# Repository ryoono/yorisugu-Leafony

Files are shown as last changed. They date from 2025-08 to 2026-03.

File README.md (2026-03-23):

# yorisugu-Leafony

MCPC主催 第6回ナノコン応用コンテスト応募作品（最優秀賞）  

## 特徴
- カメラ不要の物体認識（透過光シルエットのみで識別）
- マイコン単体（ATmega328P）でAI推論（ロジスティック回帰）
- 消費電力70mW以下（ボタン電池駆動可能）

## デモ動画
きのこの山とたけのこの里を分類する様子および技術背景をまとめた動画です。  

- ニコニコ動画: https://www.nicovideo.jp/watch/sm46081919

## 概要

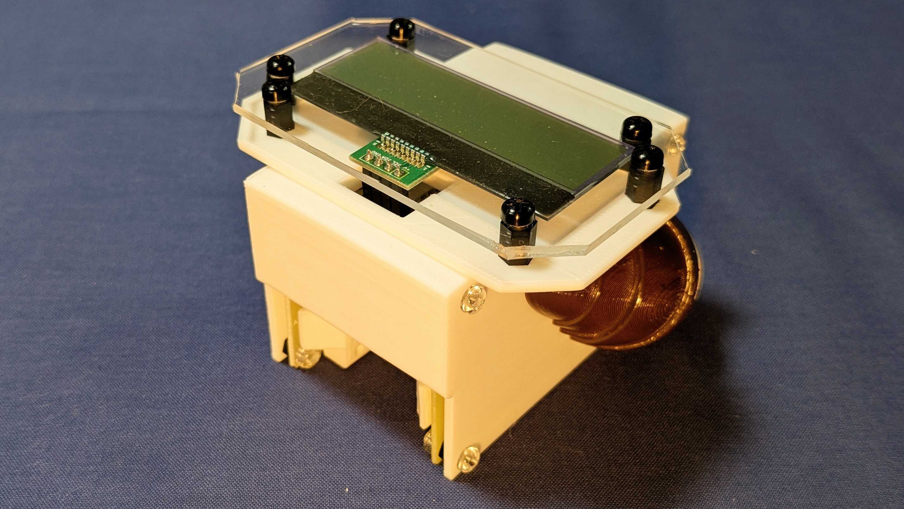
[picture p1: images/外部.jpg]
  

選りすぐLeafony  
*A low-power silhouette-based object classifier using Leafony.*  

近年、農業や製造業の現場では、形状認識のためにAIによる画像認識の導入が進んでいます。しかし、多くのシステムは高解像度カメラやGPU搭載コンピュータを必要とし、導入コストや消費電力が障壁となっています。  

本プロジェクトでは、LEDと光センサを用いて取得した「シルエット情報（透過光の強度パターン）」のみで物体を識別する、低コスト・省電力な認識手法を提案します。カメラや画像処理を使わず、マイコン1つで処理が完結するため、非常に低い消費電力で動作します。  

本プロジェクトは概念実証（PoC）として、明治製菓の「きのこの山」と「たけのこの里」を分類するデモ装置を製作し、日常的な題材を通じて技術の可能性を示しました。  

## 省電力化への取り組み

### 設計思想  
本システムではAI推論をマイコン（ATmega328P 3.3V 8MHz）上で行うことで、PCやGPUと比較して圧倒的に低い消費電力（瞬間電力70mW以内）を実現しています。これにより、ボタン電池での駆動が可能です。  

エッジAIは、計算量や精度の関係からロジスティック回帰モデルを採用しています。  

### ハードウェア設計  
マイコン1つと18個のLED/光センサによるシンプルな構成とし、最大瞬間電流を抑えるためにアナログマルチプレクサ機構を採用しています。これにより、1度に電源供給されるLED/光センサは3つで、6回に分けて電源供給されます。  

電源供給はFETで制御し、未使用時は完全に電源遮断することで待機電力を削減しています。  

### ソフトウェア設計  
本概念実証では、ひとまず1秒に1度処理を実行することとし、演算中（約3ms）以外はスリープモードにしています。  
また、シルエット情報内に物体が無いと判断された際は推論をパスし、演算時間を削減しています。  

## 回路図
基板はLED投光用と光センサ受光用の2枚が用意されます。2つの基板は向かい合わせに設置され、間にある対象物のシルエットを取得します。  

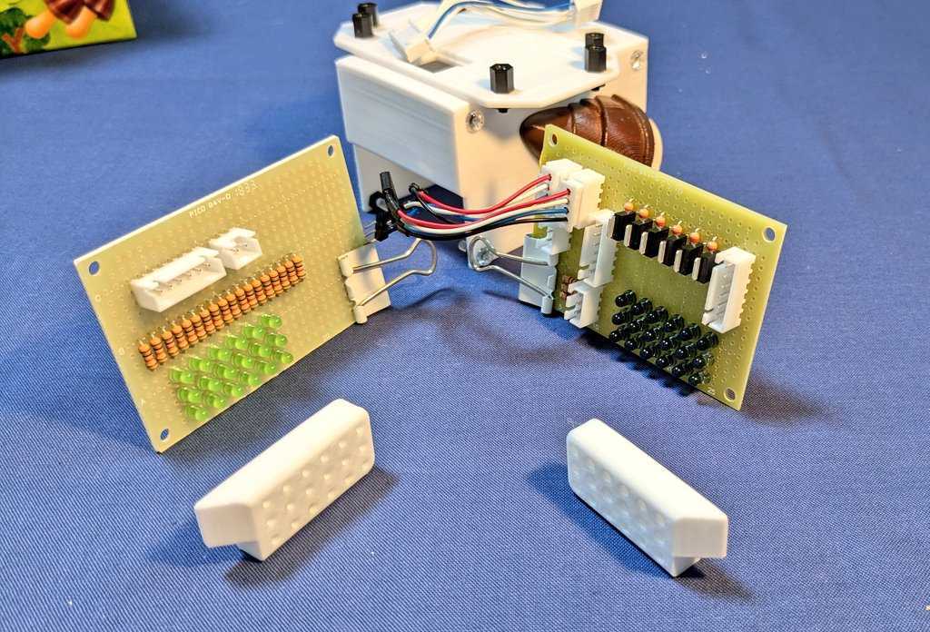
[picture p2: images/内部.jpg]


光センサ受光用基板  

  

LED投光用基板  

  

## ソフトウェア

[ソースコード](./Leafony_src/print_classification_result/)を参照

シルエットデータの取得、特徴量生成、ロジスティック回帰による推論、LCD表示を行うメイン処理です。

## 検証
本システムの有効性を確認するため、分類精度および処理性能の評価を行いました。

### データ取得
各サンプルは実機を用いて取得し、LED/光センサの出力値を特徴量として各パターンで約100ケースずつ記録しました。  
データは学習用と評価用に分割し、モデルの学習を行っています。

取得したデータをヒートマップにしたものが以下で、目視でもなんとなくお菓子のシルエットが分かります。（数値が小さい方が影）

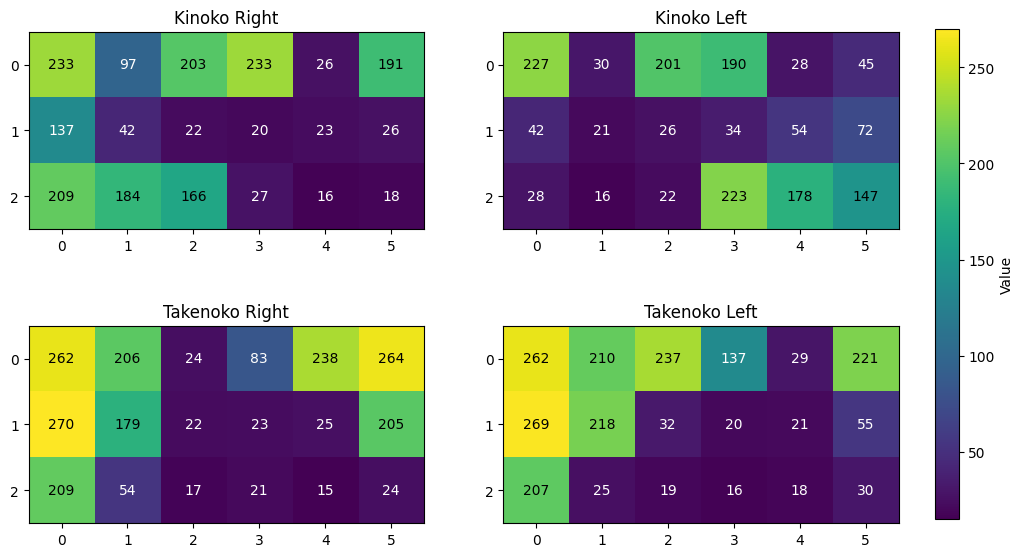
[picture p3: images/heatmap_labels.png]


### 分類結果

実機を使用して取得した[データセット](./Leafony_src/send_sens_val/raw_data/kinoko_takenoko_merged.csv)を用いてPC上で正答率を算出した結果と、結果表示画面を以下にまとめます。  

| Class | Precision | Recall | F1-score | Support |
|---:|---:|---:|---:|---:|
| 0(kinoko_right) | 1.0000 | 0.9896 | 0.9948 | 96 |
| 1(kinoko_left) | 1.0000 | 1.0000 | 1.0000 | 95 |
| 2(takenoko_right) | 0.9897 | 1.0000 | 0.9948 | 96 |
| 3(takenoko_left) | 1.0000 | 1.0000 | 1.0000 | 98 |
| **Accuracy** | — | — | **0.9974** | 385 |
| **Macro avg** | 0.9974 | 0.9974 | 0.9974 | 385 |
| **Weighted avg** | 0.9974 | 0.9974 | 0.9974 | 385 |

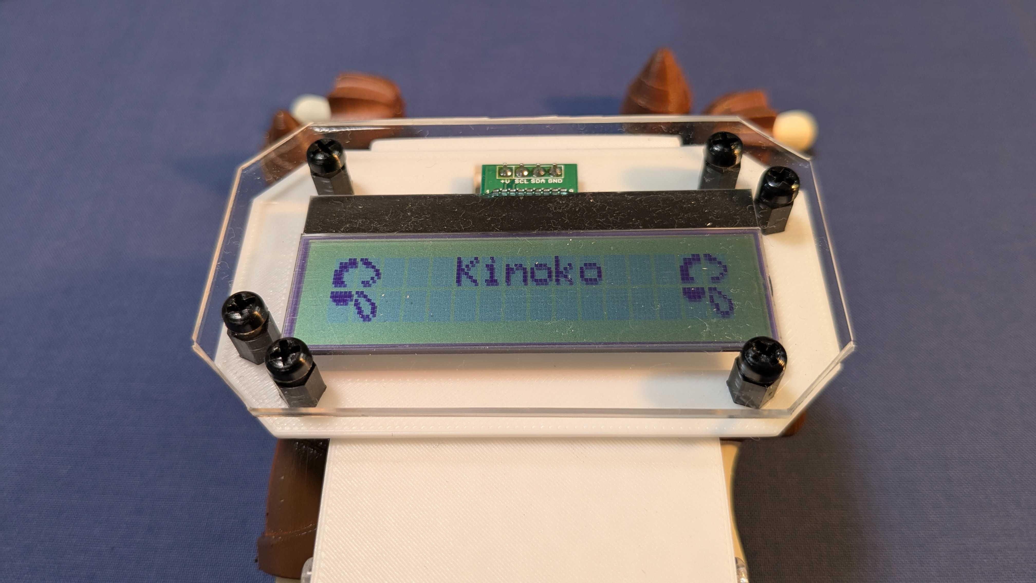
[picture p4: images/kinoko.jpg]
  

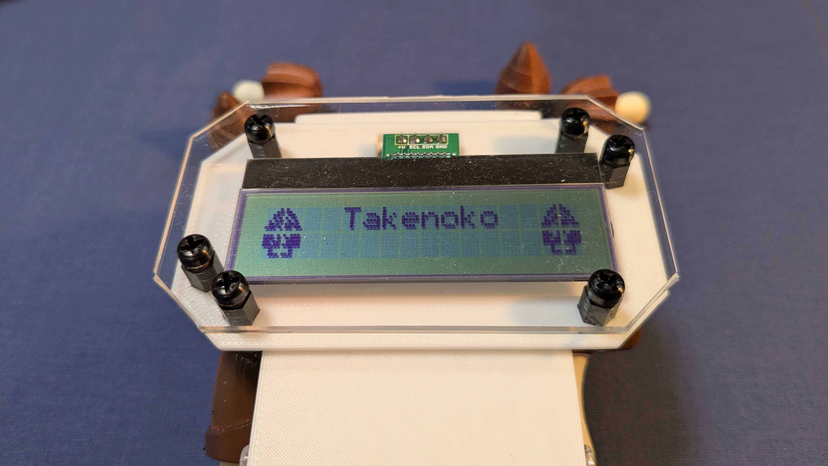
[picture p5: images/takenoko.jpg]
  

### 演算時間
シルエット取得と推論を合わせても約22msとなり、ほぼリアルタイムでの分類が可能です。

* シルエットデータ取得時間：19.23[ms]  
* 推論時間：2.98[ms]  

### 消費電流

* 消費電力（CPUアクティブ）：66.03[mW]  
* 消費電力（CPUスリープ）：5.64[mW]

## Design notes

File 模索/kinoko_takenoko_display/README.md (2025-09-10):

# きのこの山とたけのこの里を表示するサンプル  

Arduino DUEとAQM1602XA-RN-GBWで確認。

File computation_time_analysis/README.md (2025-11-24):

1ch 電流計測用(シャンク抵抗1Ω→1mVあたり1mA)
2ch D15出力

2025-11-24 23_17_00_103.bin 演算中の電流計測(D15 CPUアクティブ時間)
2025-11-24 23_23_33_606.bin 推論時間計測(D15 推論時間)

エクセルは4us単位

## 分析結果
classification_time.xls
→推論にかかる時間：2.976[ms]  

current_active.xlsx
→CPUアクティブ時間：22.208[ms]
 CPUスリープ時間：1000[ms]-22.208[ms]

→CPUアクティブ時間電流：20.01064714[mA]
 CPUスリープ時間電流：1.712257497[mA]

連続稼働時間(CR2032容量 220mAhと想定)
103.8407809[Hr]
= 4.326699206[day]

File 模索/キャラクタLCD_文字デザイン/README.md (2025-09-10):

# キャラクタLCDの文字デザイン確認ソフト

ユーザ定義文字を検討するために、絵文字を作るGUIアプリを作成。  
実行すれば動かし方は分かる。

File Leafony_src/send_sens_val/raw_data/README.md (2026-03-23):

## 取得データに関して
kinoko1:右向き(逆かも...)  
kinoko2:左向き  
takenoko1:右向き  
takenoko2:左向き  

light 蛍光灯のみ  
light_high 蛍光灯＋卓上蛍光灯  
light_dark 真っ暗  

## まとめ.csvに関して
A列はクラス番号
0:kinoko1
1:kinoko2
2:takenoko1
3:takenoko2

## ヒートマップに関して
目視確認用のヒートマップは`create_heatmap.py`で作成できる

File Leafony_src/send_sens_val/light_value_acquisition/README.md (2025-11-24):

send_sens_val.ino PCに光センサデータを送信するプログラム(Leafony ATmega328P)
receive_data2csv.py Leafonyからの光センサデータを受信してcsv保存するプログラム

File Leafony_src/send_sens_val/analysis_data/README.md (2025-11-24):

光センサ値(生値)を標準化する

y.npy	ラベル配列（分類 0〜3）
X_std.npy	標準化済み特徴量
scaler_params.npz	mean / scale（標準化吸収計算に必要）

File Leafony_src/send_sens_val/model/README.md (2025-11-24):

光センサ値(標準化後)からロジスティック回帰モデルを学習する
精度とヘッダーファイルも出力する

```sh
> py .\create_model.py
Loaded: y=(1282,), X_std=(1282, 18)
mean:  [228.67082683 137.15834633 134.01716069 179.26287051 132.57020281
 219.83229329 196.00312012  90.92589704  37.0850234   26.46021841
  64.36193448 137.5374415  176.32527301  70.90327613  49.29017161
  37.66926677  42.40015601  68.46021841]
scale: [ 60.48383372  79.93528416 100.38204564  87.08588841 110.11716984
 109.06033533  97.47125656  90.3870597   52.61642415  27.63440381
  71.26954429 102.64351736  54.24962067  74.27554429  60.2451185
  59.54423734  58.3866538   65.56794044]
Train: X=(897, 18), Test: X=(385, 18)
C:\Users\k1602\AppData\Local\Programs\Python\Python313\Lib\site-packages\sklearn\linear_model\_logistic.py:1247: FutureWarning: 'multi_class' was deprecated in version 1.5 and will be removed in 1.7. From then on, it will always use 'multinomial'. Leave it to its default value to avoid this warning.
  warnings.warn(
====================================
Multiclass Logistic Regression (trained on X_std)
Accuracy: 0.9974
====================================
Classification report:
              precision    recall  f1-score   support

           0     1.0000    0.9896    0.9948        96
           1     1.0000    1.0000    1.0000        95
           2     0.9897    1.0000    0.9948        96
           3     1.0000    1.0000    1.0000        98

    accuracy                         0.9974       385
   macro avg     0.9974    0.9974    0.9974       385
weighted avg     0.9974    0.9974    0.9974       385

Header file written to: logistic_params_raw.h
```

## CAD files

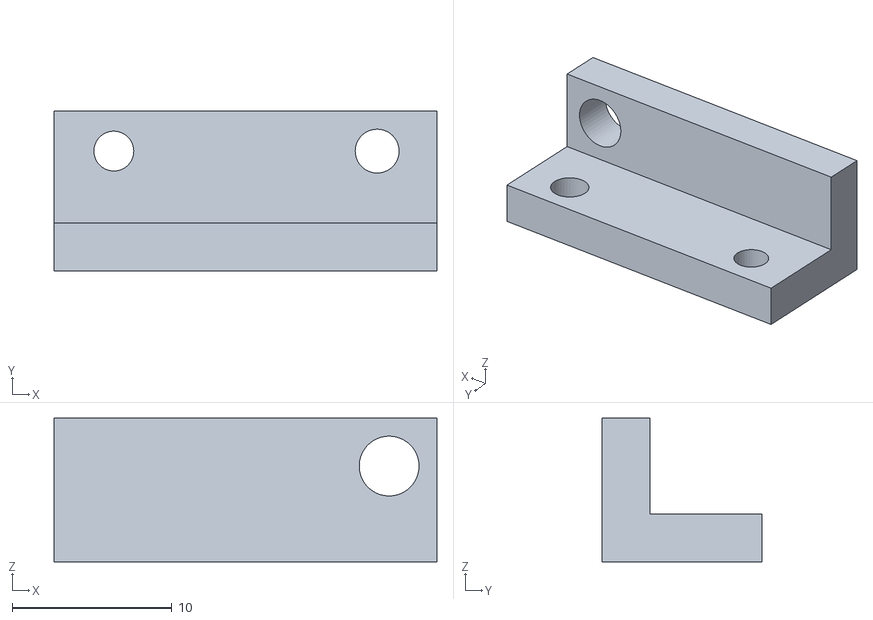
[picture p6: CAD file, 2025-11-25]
3d_data/Leafony固定治具.stl
24.0 x 10.0 x 9.00

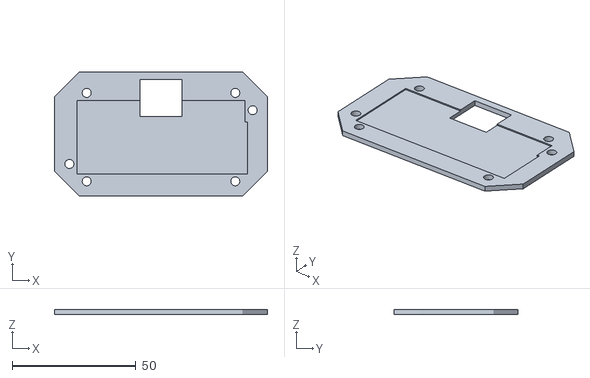
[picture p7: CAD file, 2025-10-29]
3d_data/LCD台.stl
86.0 x 50.2 x 2.00

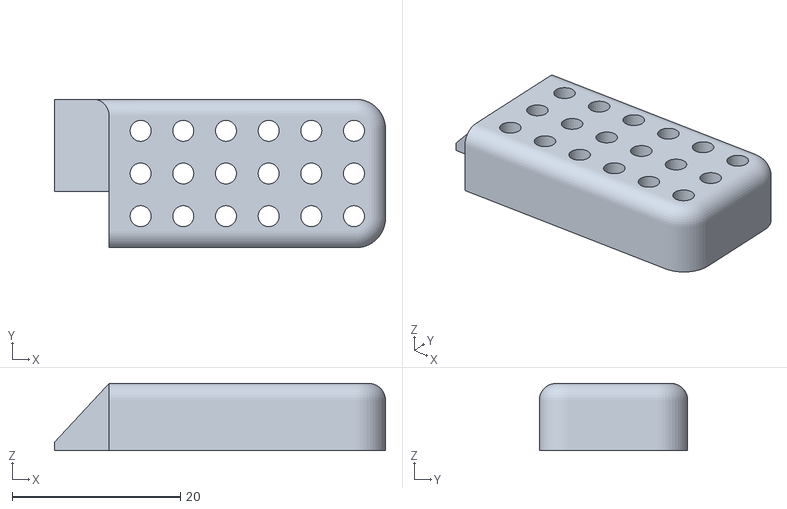
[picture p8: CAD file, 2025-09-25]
3d_data/固定台2.stl
39.4 x 17.7 x 8.00

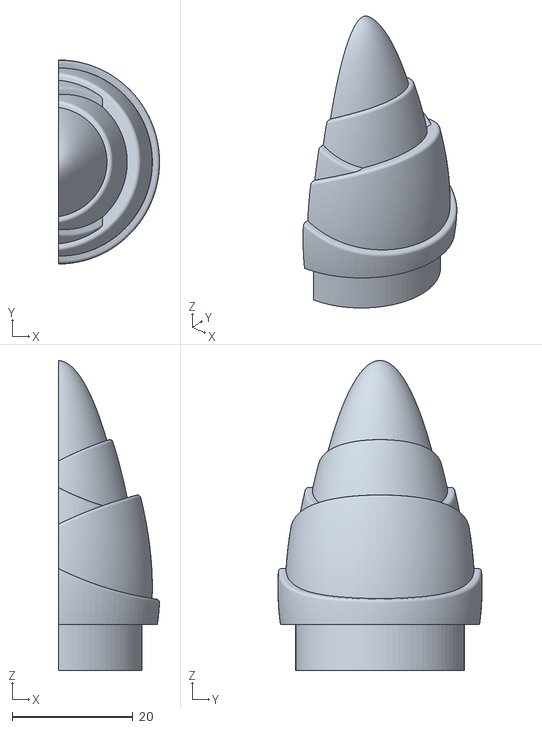
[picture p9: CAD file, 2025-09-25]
3d_data/たけのこ_ハーフ.stl
16.8 x 33.8 x 51.4

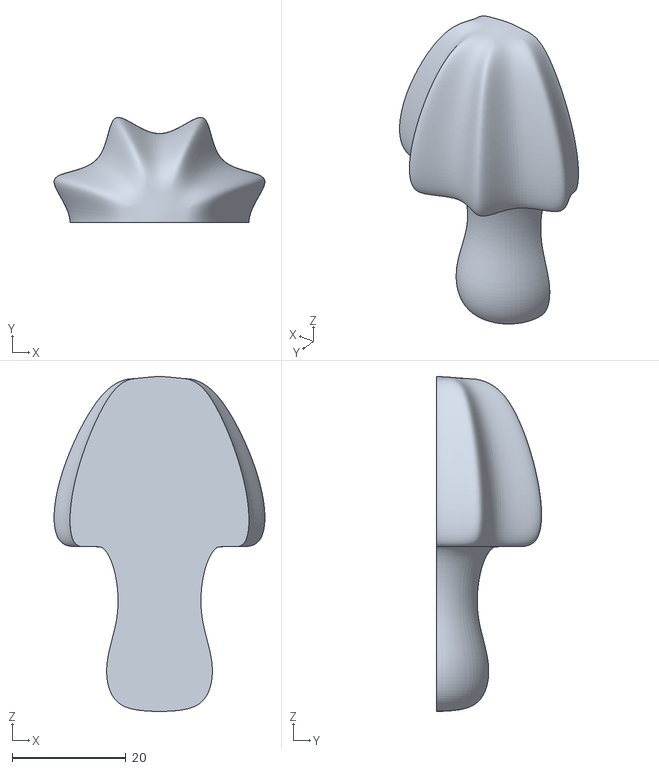
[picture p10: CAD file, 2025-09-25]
3d_data/きのこ_ハーフ.stl
37.1 x 18.5 x 59.0

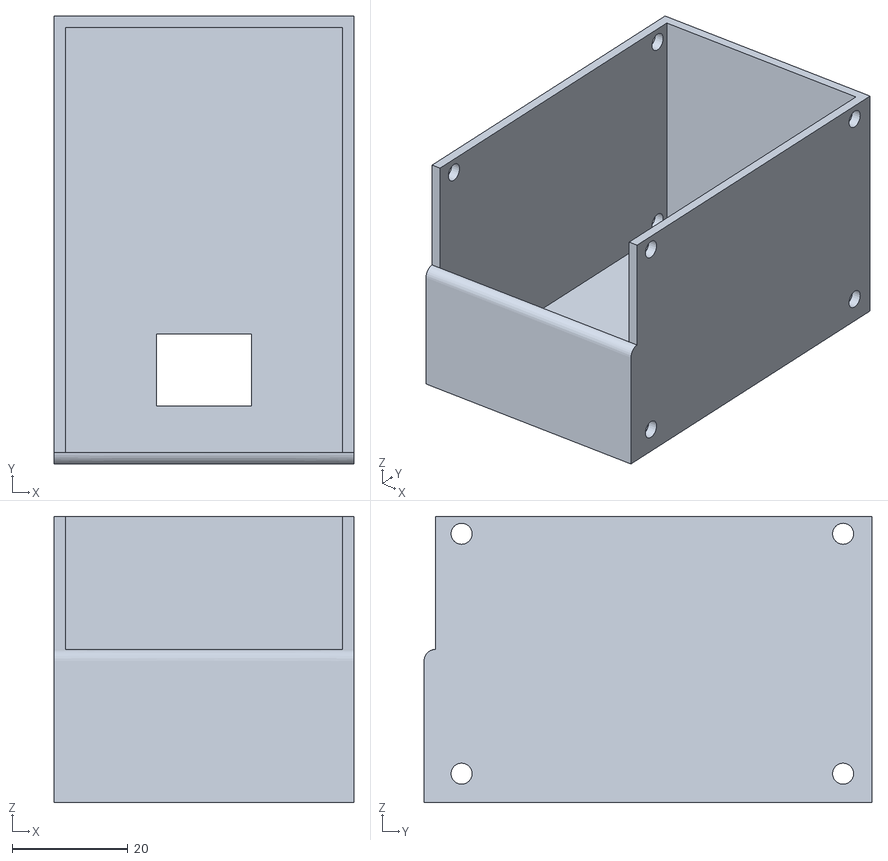
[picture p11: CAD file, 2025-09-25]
3d_data/基板固定_ボディ.stl
51.9 x 77.5 x 49.5

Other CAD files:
3d_data/固定台1.stl

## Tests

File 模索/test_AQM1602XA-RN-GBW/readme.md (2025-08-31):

# 消費電流調査用  

## 調査項目  

以下条件で調査  

Arduino DUE(Leafonyと同じく3.3V駆動にしたかったため)

コントラスト(0~63, 7刻み)  

・全消灯
・ABC...  
・半分点灯  
・消灯  

## 結果  

直流安定化電源の3.3Vを入れて、テスターの電流計で計測  
最大0.24mAほどとなり、CR2032(3V)から3.3Vに昇圧することを考えても問題なさそう  
0.24[mA] * 3.3[V]/3[V] / 0.8(変換効率) = 0.33[mA]

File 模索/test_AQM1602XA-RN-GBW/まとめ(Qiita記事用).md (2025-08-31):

# LCD(AE-AQM1602A)の消費電流を実測してみた

LCD / AE-AQM1602A / Arduino / CR2032 / 電子工作

## 結論

LCD(AE-AQM1602A)の消費電流を計測したところ、0.25[mA]ほどであり、ボタン電池でも十分駆動可能であることが分かりました。  

本記事は、低消費電力で動作するディスプレイを探している電子工作初心者や、省電力IoTデバイス開発者向けの記事です。

## はじめに

前回、ボタン電池でOLEDが駆動できるか確認したが、数十mA以上必要ということが分かり、ボタン電池駆動は出来ないと結論付けた。  

https://qiita.com/TetoraTechLab/items/b2971745c7ca7f4c60e8

そこで、一般的なLCDである「AE-AQM1602A」(1mA@3.3V)を使用しようと考えたのだが、OLEDの件もあり「本当にこんなに電流低いのか...？」と疑心暗鬼となってしまった。そのため、電流を計測してみることにする。  

https://akizukidenshi.com/catalog/g/g108896/

## ハードウェア

試作ではLeafony※と電圧レベルを合わせるために、同じ3.3V出力の「Arduino DUE」を使用している。  

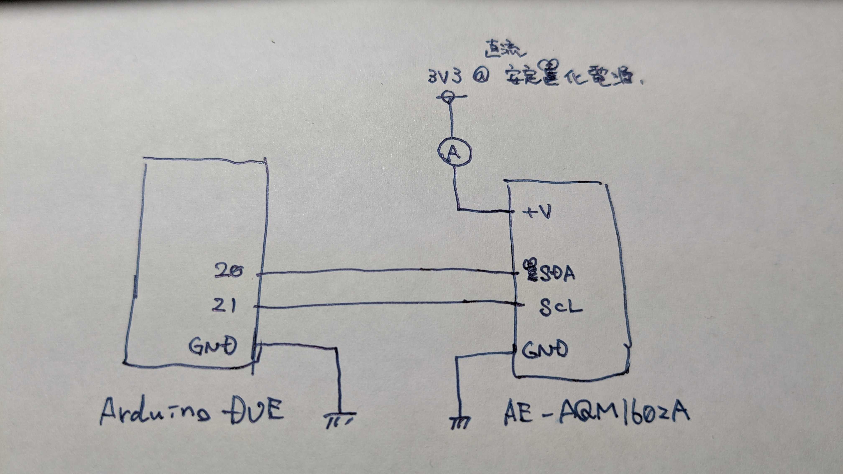
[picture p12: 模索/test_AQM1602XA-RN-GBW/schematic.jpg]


※：Leafonyとは、超小型・低消費電力の電子基板モジュール  

https://docs.leafony.com/docs/overview/#leafony%E3%81%A8%E3%81%AF

使用した電流計(テスター)は以下(3mA計測のレンジを使用)  

https://www.nisic.co.jp/products/electric/multimeter/model-5230-01-%E3%83%86%E3%82%B9%E3%82%BF/

## ソフトウェア

消費電力を計測するにあたり、全部点灯している場合と半分点灯している場合が見たかったため、ユーザ定義の文字を作成しています。  

<details><summary>消費電力計測用のプログラム</summary>

```cpp
#include <Wire.h>
#define LCD_ADRS 0x3E  // AQM1602XA I2Cアドレス

// 表示状態：消灯 → 半分点灯(下) → 全点灯 → 文字サンプル
enum DispState : uint8_t { ALL_OFF = 0, HALF_ON = 1, FULL_ON = 2, CHAR_SAMPLE = 3 };
DispState state = ALL_OFF;

int  contrastVal = 0;    // 0..63, 'c'で+7

// ---- 基本I2C送信 ----
static inline void writeCommand(uint8_t cmd) {
  Wire.beginTransmission(LCD_ADRS);
  Wire.write(0x00);  // Co=0, RS=0
  Wire.write(cmd);
  Wire.endTransmission();
  delay(2);
}
static inline void writeData(uint8_t data) {
  Wire.beginTransmission(LCD_ADRS);
  Wire.write(0x40);  // Co=0, RS=1
  Wire.write(data);
  Wire.endTransmission();
  delay(1);
}

// ---- 初期化 ----
void init_LCD() {
  delay(50);
  writeCommand(0x38);     // Function set
  writeCommand(0x39);     // IS=1
  writeCommand(0x14);     // Bias/OSC (初期は1/5 bias)
  writeCommand(0x70 | (contrastVal & 0x0F));          // Contrast low
  writeCommand(0x5C | ((contrastVal >> 4) & 0x03));   // Contrast high, Icon off, Booster on
  writeCommand(0x6C);     // Follower ON
  delay(200);
  writeCommand(0x38);     // IS=0
  writeCommand(0x0C);     // Display ON
  writeCommand(0x01);     // Clear
  delay(2);
  writeCommand(0x06);     // Entry mode
}

// ---- CGRAM定義 ----
// コード0: 5x8 全点灯
void defineFullOnChar() {
  writeCommand(0x40);     // CGRAM addr = 0（キャラ0）
  for (int i = 0; i < 8; i++) writeData(0x1F);
}

// コード1: 下半分のみ点灯（行4〜7を0x1F、行0〜3は0x00）
void defineHalfOnCharBottom() {
  writeCommand(0x40 | 0x08); // CGRAM addr = 8（キャラ1の先頭）
  for (int i = 0; i < 4; i++) writeData(0x00); // 上半分 消灯
  for (int i = 0; i < 4; i++) writeData(0x1F); // 下半分 点灯
}

// ---- DDRAM全域を指定コードで埋める（16x2） ----
void lcdFillAll(uint8_t code) {
  writeCommand(0x80 | 0x00);
  for (int i = 0; i < 16; i++) writeData(code);
  writeCommand(0x80 | 0x40);
  for (int i = 0; i < 16; i++) writeData(code);
}

// ---- 全消灯（空白で埋め→Clear） ----
void lcdAllOff() {
  lcdFillAll(0x20);   // 空白で埋める（0b0010_0000）
  writeCommand(0x01); // Clear Display（DDRAM全消去＋ホーム）
  delay(2);
}

// ---- 半分点灯（コード1） ----
void lcdHalfOn() {
  lcdAllOff();
  lcdFillAll(0x01); // CGRAM[1]
}

// ---- 全点灯（コード0） ----
void lcdAllOn() {
  lcdAllOff();
  lcdFillAll(0x00); // CGRAM[0]
}

// ---- キャラクタサンプル表示（"ABCDEFGHIJKLMNOP" / "QRSTUVWXYZabcdef"） ----
void lcdCharSample() {
  lcdAllOff();
  const char line1[17] = "ABCDEFGHIJKLMNOP";     // 16文字
  const char line2[17] = "QRSTUVWXYZabcdef";     // 16文字（A..Zの続きに a..f）
  writeCommand(0x80 | 0x00);                     // 1行目先頭
  for (int i = 0; i < 16; i++) writeData(line1[i]);
  writeCommand(0x80 | 0x40);                     // 2行目先頭
  for (int i = 0; i < 16; i++) writeData(line2[i]);
}

// ---- コントラスト設定 ----
void setContrast(int val) {
  val = constrain(val, 0, 63);
  writeCommand(0x39); // IS=1
  writeCommand(0x70 | (val & 0x0F));
  writeCommand(0x5C | ((val >> 4) & 0x03));
  writeCommand(0x38); // IS=0
}

// ---- 状態適用：再描画 ----
void applyState() {
  switch (state) {
    case ALL_OFF:    lcdAllOff();     Serial.println(F("ALL-OFF")); break;
    case HALF_ON:    lcdHalfOn();     Serial.println(F("HALF-ON (bottom half)")); break;
    case FULL_ON:    lcdAllOn();      Serial.println(F("FULL-ON")); break;
    case CHAR_SAMPLE:lcdCharSample(); Serial.println(F("CHAR-SAMPLE (A..Z then a..f)")); break;
  }
}

void setup() {
  Serial.begin(115200);
  Wire.begin();             // Due: SDA=20, SCL=21
  init_LCD();
  defineFullOnChar();
  defineHalfOnCharBottom();
  applyState();    // 初期 ALL_OFF
  Serial.println(F("Ready. 'r': OFF -> HALF -> FULL -> SAMPLE,  'c': Contrast +7"));
}

void loop() {
  if (Serial.available()) {
    char c = Serial.read();
    if (c == 'r' || c == 'R') {
      state = static_cast<DispState>((state + 1) % 4); // OFF→HALF→FULL→SAMPLE→OFF…
      applyState();
    }
    else if (c == 'c' || c == 'C') {
      contrastVal += 7;
      if (contrastVal > 63) contrastVal = 0;
      setContrast(contrastVal);
      Serial.print(F("Contrast = "));
      Serial.println(contrastVal);
    }
  }
}
```

</details>

## 計測結果

### 計測環境

以下の環境で実施した。(実際に計測される方は、導通部分に絶縁テープを貼るなどして、短絡を防止してください。)  

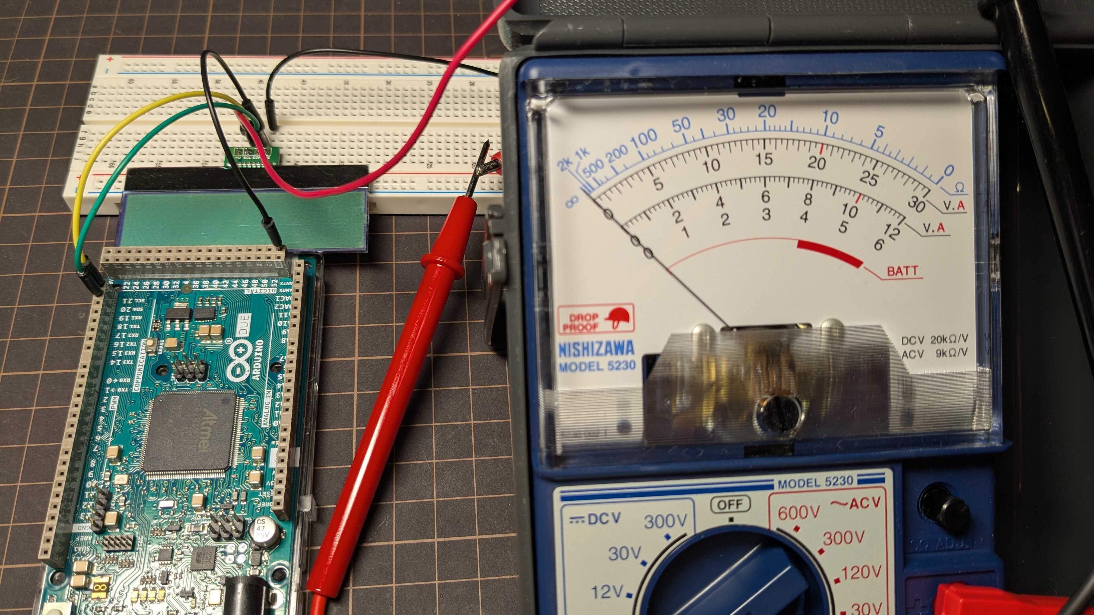
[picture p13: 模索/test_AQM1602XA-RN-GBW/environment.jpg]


計測は以下の4パターンで計測した。コントラストは0~63の範囲で7刻みで計測した。  

* 消灯

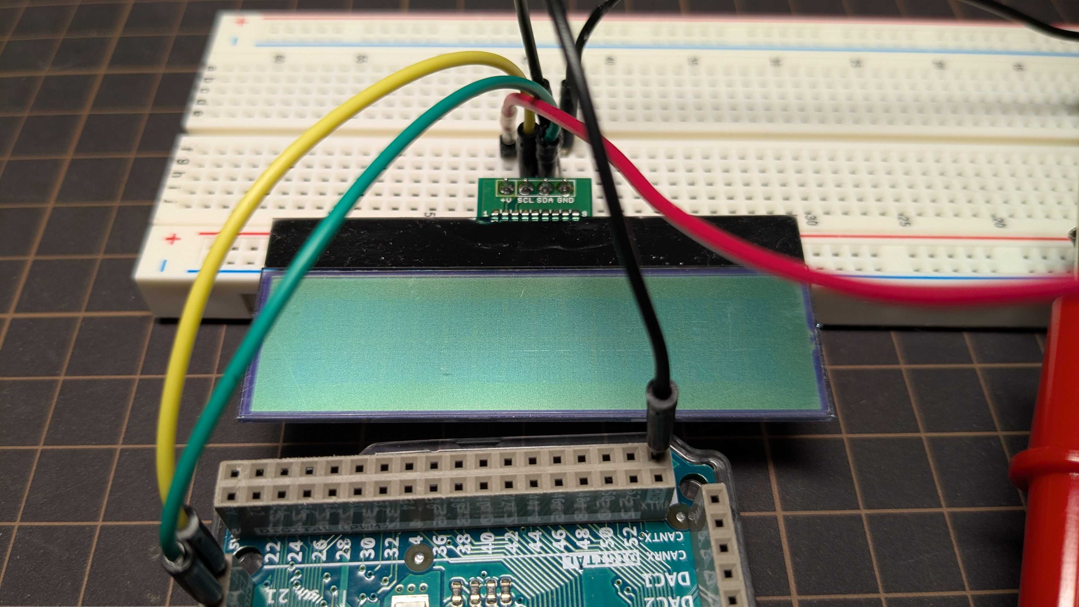
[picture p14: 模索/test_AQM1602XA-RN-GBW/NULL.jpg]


* 半分点灯(ユーザ定義文字)

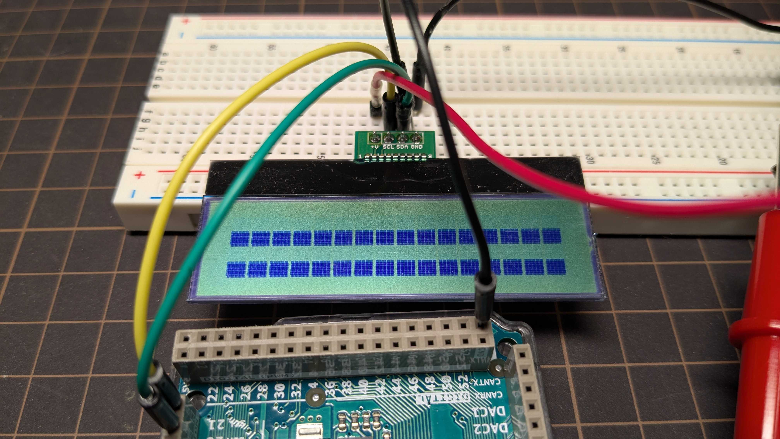
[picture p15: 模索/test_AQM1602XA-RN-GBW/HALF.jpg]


* 全点灯(ユーザ定義文字)

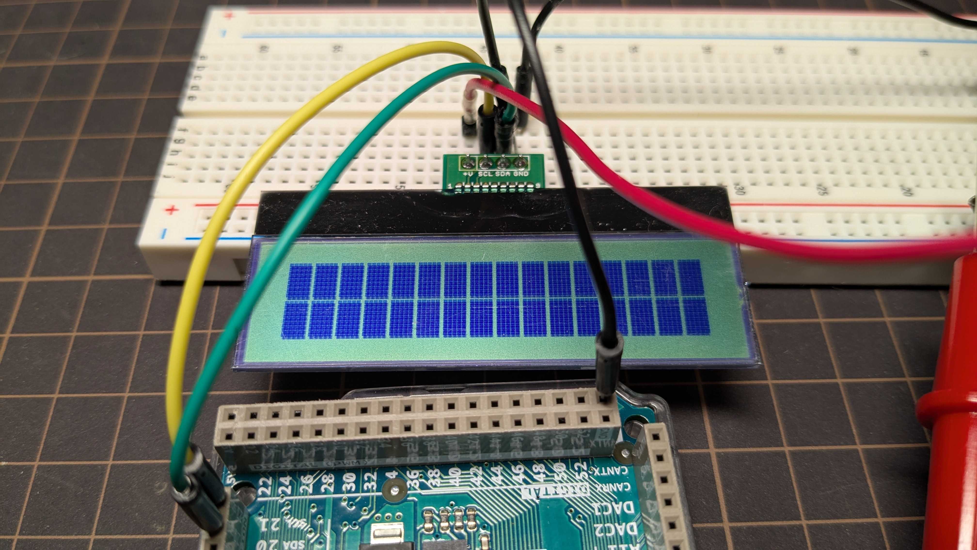
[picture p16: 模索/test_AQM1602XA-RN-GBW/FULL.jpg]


* 文字サンプル出力

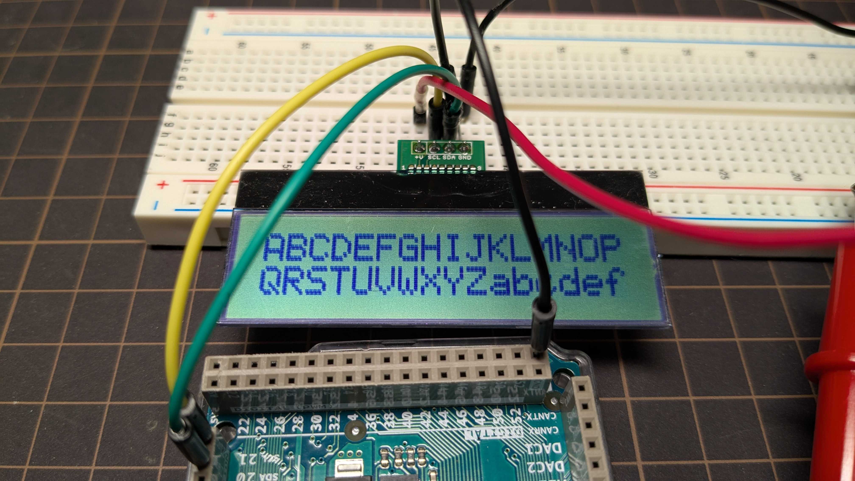
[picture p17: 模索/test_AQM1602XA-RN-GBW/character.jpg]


### 電流計測値

以下の通りとなった。何故か半分点灯時の電流が全点灯時の電流よりも大きかったが、最大でも0.25mA以下で、非常に小さな電流で駆動することが分かった。(仕様書に書いてあった1mA@3.3Vを大幅に下回った)

また、ボタン電池(3V)を3.3Vに昇圧して用いることを考慮しても、「ボタン電池の出力電流 = 0.25[mA] * [3.3[V]]/3[V] / 0.8(効率) <= 0.35[mA]」となり、ボタン電池駆動可能と考えられる。  

| コントラスト | 0 | 7 | 14 | 21 | 28 | 35 | 42 | 49 | 56 | 63 | [deg] (MAX：63) | 
| --- | ---- | ---- | ---- | ---- | ---- | ---- | ---- | ---- | ---- | ---- | --- |
| 消灯 | 0.14 | 0.14 | 0.14 | 0.14 | 0.15 | 0.15 | 0.15 | 0.17 | 0.19 | 0.19 | [mA] | 
| 半分点灯 | 0.14 | 0.15 | 0.15 | 0.16 | 0.17 | 0.19 | 0.2  | 0.21 | 0.24 | 0.24 | [mA] | 
| 全点灯 | 0.14 | 0.14 | 0.14 | 0.14 | 0.15 | 0.17 | 0.17 | 0.19 | 0.19 | 0.20 | [mA] | 
| ABC… | 0.14 | 0.15 | 0.15 | 0.16 | 0.17 | 0.18 | 0.19 | 0.20 | 0.21 | 0.22 | [mA] | 

※：コントラスト14あたりまでは薄すぎて見えない。逆に49を超えると濃すぎて見えない。

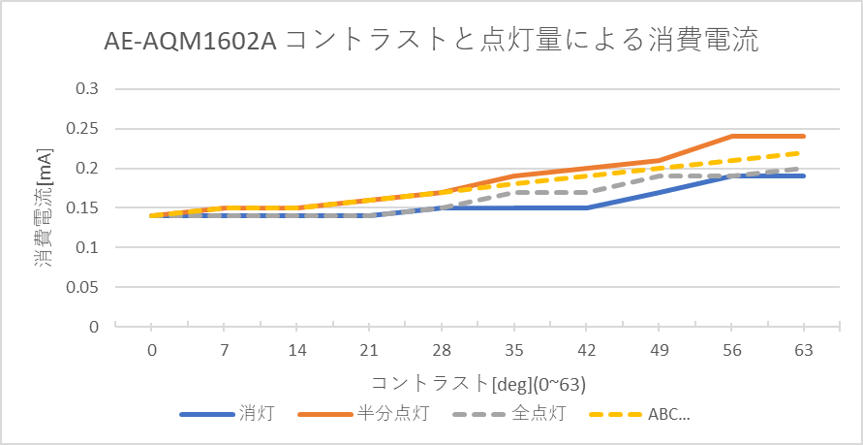
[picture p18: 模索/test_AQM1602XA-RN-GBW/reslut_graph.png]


## まとめ

Leafonyのコンテストに出すために、ディスプレイを試行錯誤していましたが、このLCDを使用することにします。  
ちなみに、今回はバックライト無しのLCDを使用していますが、バックライトありのLCDですと、バックライト分の電流が上乗せされます。そのため、省電力で用いたい場合はバックライト無しを選択する必要があります。(バックライトはLEDであることが多く、普通に数mA以上流れます。)

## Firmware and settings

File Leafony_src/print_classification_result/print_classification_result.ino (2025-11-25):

// チップ：ATmega328P 3.3V 8MHz 
// パッケージ：Leafony

#include <Wire.h>
#define LCD_ADRS 0x3E  // AQM1602XA I2Cアドレス
#define LCD_COLS 16

// ★ 省電力用：スリープ＆割り込み
#include <avr/sleep.h>
#include <avr/interrupt.h>

// ★ デバッグ用：演算時間計測ピン（D5）
// 必要ならスケッチの先頭などで #define DEBUG を有効化する
// #define DEBUG
#ifdef DEBUG
  #define DEBUG_PIN 5
#endif

// ★ ロジスティック回帰のパラメータ（標準化吸収済み, 生ADC値用）
#include "logistic_params_raw.h"

// ---- ピン定義 ----
static const uint8_t OUTPUT_PINS[] = {6, 7, 8, A3, 9, 10};
static const uint8_t INPUT_PINS[]  = {A0, A1, A2};
static const uint8_t NUM_OUT = sizeof(OUTPUT_PINS) / sizeof(OUTPUT_PINS[0]);
static const uint8_t NUM_IN  = sizeof(INPUT_PINS)  / sizeof(INPUT_PINS[0]);

// 3(入力) x 6(出力) の読み取り結果バッファ
static uint16_t adc[3][6];  // adc[row(in), col(out)]

// OUTPUT_PINS の各要素に対応するポートレジスタとビット
static volatile uint8_t* const OUTPUT_PORTS[NUM_OUT] = {
  &PORTD, &PORTD, &PORTB, &PORTC, &PORTB, &PORTB
};
static const uint8_t OUTPUT_BITS[NUM_OUT] = {
  _BV(PD6), _BV(PD7), _BV(PB0), _BV(PC3), _BV(PB1), _BV(PB2)
};

// 高速版 digitalWrite 相当
static inline void fastWriteHigh(uint8_t idx) {
  *OUTPUT_PORTS[idx] |= OUTPUT_BITS[idx];
}
static inline void fastWriteLow(uint8_t idx) {
  *OUTPUT_PORTS[idx] &= ~OUTPUT_BITS[idx];
}

// 表示状態
enum DispState : uint8_t {
  STATE_OFF = 0,
  STATE_TAKENOKO = 1,
  STATE_KINOKO  = 2,
  STATE_NOT_FOUND = 3
};
DispState g_state = STATE_OFF;
DispState g_state_buf = STATE_OFF;

// ---- 固定コントラスト ----
static const uint8_t FIXED_CONTRAST = 35; // 0..63

// ---- 低レベル送信 ----
static inline void writeCommand(uint8_t cmd) {
  Wire.beginTransmission(LCD_ADRS);
  Wire.write(0x00);  // Co=0, RS=0
  Wire.write(cmd);
  Wire.endTransmission();
  delayMicroseconds(500);
}
static inline void writeData(uint8_t data) {
  Wire.beginTransmission(LCD_ADRS);
  Wire.write(0x40);  // Co=0, RS=1
  Wire.write(data);
  Wire.endTransmission();
  delayMicroseconds(500);
}

// ---- 便利ヘルパー ----
static inline void setCursor(uint8_t col, uint8_t row) {
  writeCommand(0x80 | (row ? (0x40 + col) : col));
}
static inline void writeAsciiStr(const char* s) { while (*s) writeData((uint8_t)*s++); }
static inline void writeSpaces(uint8_t n) { for (uint8_t i = 0; i < n; ++i) writeData(0x20); }
static inline void putCGRAM(uint8_t code) { writeData(code & 0x07); }

// ---- ピン初期化 ----
void initPins() {
  for (uint8_t i = 0; i < NUM_OUT; ++i) {
    pinMode(OUTPUT_PINS[i], OUTPUT);
    fastWriteHigh(i);
  }
  for (uint8_t i = 0; i < NUM_IN; ++i) {
    pinMode(INPUT_PINS[i], INPUT); // 外付けプルダウン
  }

#ifdef DEBUG
  // D5 を演算時間計測用の出力にする
  pinMode(DEBUG_PIN, OUTPUT);
  digitalWrite(DEBUG_PIN, LOW);
#endif
}

// ---- LCD初期化 ----
void initLCD() {
  delay(50);
  writeCommand(0x38);
  writeCommand(0x39);
  writeCommand(0x14);
  writeCommand(0x70 | (FIXED_CONTRAST & 0x0F));
  writeCommand(0x5C | ((FIXED_CONTRAST >> 4) & 0x03));
  writeCommand(0x6C);
  delay(200);
  writeCommand(0x38);
  writeCommand(0x0C);
  writeCommand(0x01);
  delay(2);
  writeCommand(0x06);
}

// ---- CGRAM定義 ----
void defineCGRAMAll() {
  const uint8_t CGRAMs[8][8] = {
    { 0x03, 0x0F, 0x0C, 0x18, 0x18, 0x18, 0x1C, 0x00 },
    { 0x18, 0x0C, 0x02, 0x01, 0x01, 0x02, 0x0C, 0x00 },
    { 0x1F, 0x1F, 0x0E, 0x00, 0x00, 0x00, 0x00, 0x00 },
    { 0x18, 0x04, 0x12, 0x11, 0x09, 0x09, 0x06, 0x00 },
    { 0x01, 0x03, 0x06, 0x05, 0x0B, 0x0E, 0x1D, 0x00 },
    { 0x10, 0x18, 0x0C, 0x14, 0x0A, 0x1E, 0x1B, 0x00 },
    { 0x1D, 0x1D, 0x1B, 0x1F, 0x04, 0x04, 0x07, 0x00 },
    { 0x17, 0x0F, 0x0F, 0x1F, 0x04, 0x04, 0x1C, 0x00 }
  };
  for (uint8_t ch = 0; ch < 8; ++ch) {
    writeCommand(0x40 | ((ch & 0x07) << 3));
    for (uint8_t r = 0; r < 8; ++r) writeData(CGRAMs[ch][r] & 0x1F);
  }
}

// ---- 画面クリア ----
void lcdClearAll() {
  setCursor(0, 0); for (int i = 0; i < LCD_COLS; ++i) writeData(0x20);
  setCursor(0, 1); for (int i = 0; i < LCD_COLS; ++i) writeData(0x20);
  writeCommand(0x01);
  delayMicroseconds(500);
}

// ---- パターン ----
void drawKinokoPattern() {
  lcdClearAll();
  setCursor(0, 0);
  putCGRAM(0); putCGRAM(1);
  writeSpaces(3);
  writeAsciiStr("Kinoko");
  writeSpaces(3);
  putCGRAM(0); putCGRAM(1);
  setCursor(0, 1);
  putCGRAM(2); putCGRAM(3);
  writeSpaces(12);
  putCGRAM(2); putCGRAM(3);
}
void drawTakenokoPattern() {
  lcdClearAll();
  setCursor(0, 0);
  putCGRAM(4); putCGRAM(5);
  writeSpaces(2);
  writeAsciiStr("Takenoko");
  writeSpaces(2);
  putCGRAM(4); putCGRAM(5);
  setCursor(0, 1);
  putCGRAM(6); putCGRAM(7);
  writeSpaces(12);
  putCGRAM(6); putCGRAM(7);
}
void drawNotFoundPattern() {
  lcdClearAll();
  setCursor(0, 0);

  const char* msg = "Not Found";
  const uint8_t len = 9;                 // "Not Found" の文字数
  uint8_t left = (LCD_COLS - len) >> 1;  // ÷2（中央寄せ用）

  // 1行目中央に "Not Found" を表示
  writeSpaces(left);
  writeAsciiStr(msg);
  // 残りは lcdClearAll() 済みなので特に何もしなくてOK
}

// ---- 状態適用 ----
void printResult() {
  switch (g_state) {
    case STATE_OFF:       lcdClearAll();         break;
    case STATE_TAKENOKO:  drawTakenokoPattern(); break;
    case STATE_KINOKO:    drawKinokoPattern();   break;
    case STATE_NOT_FOUND: drawNotFoundPattern(); break;
  }
}

// 何もない場合の判定 学習データ最大(2977)より少し大きい値にしておく
const uint16_t NO_OBJECT_THRESHOLD = 3200;

// ★ 1秒ごとに計測処理を実行するためのフラグ（Timer1割り込みでセット）
volatile bool g_do_measure = false;

// ★ 光センサ値(adc[3][6])からラベル(0〜3)を推論
int predictLabelFromAdc() {
  float x[LOGI_NUM_FEATURES];
  uint8_t idx = 0;

  // 学習時と同じ並び順（行優先: r→c）で18要素にフラット化
  for (uint8_t r = 0; r < NUM_IN; ++r) {
    for (uint8_t c = 0; c < NUM_OUT; ++c) {
      // NUM_IN * NUM_OUT == LOGI_NUM_FEATURES(18) 固定なので境界チェックは不要
      x[idx++] = (float)adc[r][c];   // 生のanalogRead値をそのまま使う
    }
  }

  float best_score = -1.0e30f;
  int   best_k     = 0;

  for (uint8_t k = 0; k < LOGI_NUM_CLASSES; ++k) {
    float z = LOGI_B[k];
    for (uint8_t i = 0; i < LOGI_NUM_FEATURES; ++i) {
      z += LOGI_W[k][i] * x[i];
    }
    if (k == 0 || z > best_score) {
      best_score = z;
      best_k     = (int)k;
    }
  }
  return best_k;
}

// ★ Timer1 を 1Hz（1秒ごと）CTC割り込みに設定
void initTimer1_1Hz() {
  cli();              // 割り込み一時禁止

  TCCR1A = 0;
  TCCR1B = 0;
  TCNT1  = 0;

  // CTCモード (WGM12 = 1)
  TCCR1B |= (1 << WGM12);

  // 8MHz / 1024 = 7812.5 Hz → 約1秒ごとに割り込み
  OCR1A = 7812;  // 1秒弱だが展示用途なら十分

  // プリスケーラ 1024 設定 (CS12=1, CS10=1)
  TCCR1B |= (1 << CS12) | (1 << CS10);

  // 比較一致A割り込み許可
  TIMSK1 |= (1 << OCIE1A);

  sei();              // 割り込み許可
}

// ★ Timer1 比較一致A割り込みハンドラ：フラグを立てるだけ
ISR(TIMER1_COMPA_vect) {
  g_do_measure = true;
}

// 物体認識と結果表示関数
void runSensorScanAndInference(){


  uint16_t adc_sum = 0; // 何もない場合を判定するための、ADC合計値

  // FETを順にONし、光センサを3つずつ読み込む(6列分)
  for (uint8_t j = 0; j < NUM_OUT; ++j) {

    // 対象の列だけ LOW(FET ON)
    fastWriteLow(j);   // ★ digitalWrite → レジスタ直叩き

    // （必要ならRC安定待ち）
    delayMicroseconds(2500);

    // このタイミングで INPUT を1回ずつ読む（列 j に格納）
    for (uint8_t r = 0; r < NUM_IN; ++r) {
      (void)analogRead(INPUT_PINS[r]);           // 捨て読み（ADC内部の前回値を追従させる）
      adc[r][j] = analogRead(INPUT_PINS[r]);
      adc_sum += adc[r][j];
    }

    // 対象の列だけ HIGH(FET OFF)
    fastWriteHigh(j);  // ★ digitalWrite → レジスタ直叩き
  }

  // 最後の列（index=5）を読んだ直後に、推論 & LCD出力処理
  // 物体が何もない場合は、推論をしない
  // LCD表示が前回と変更ない場合は、出力しない
  if (adc_sum >= NO_OBJECT_THRESHOLD) { // 物体が何もない場合
    g_state = STATE_NOT_FOUND;
  }
  else { // 物体がある場合
#ifdef DEBUG
  // ★ 計測開始：D5(HIGH)
  PORTD |= _BV(PD5);
#endif
    int label = predictLabelFromAdc();
#ifdef DEBUG
  // ★ 計測終了：D5(LOW)
  PORTD &= ~_BV(PD5);
#endif
    if ((label == 0) || (label == 1))  g_state = STATE_KINOKO;
    else                               g_state = STATE_TAKENOKO;
  }

  if (g_state != g_state_buf)  printResult();
  g_state_buf = g_state;
}

void setup() {
  // Serial.begin(115200);
  Wire.begin();
  initPins();
  initLCD();
  defineCGRAMAll();

  g_state = STATE_OFF;
  printResult();

  // ★ 1秒タイマ割り込みの初期化
  initTimer1_1Hz();
}

void loop() {
  // ===== スリープ =====
  if (!g_do_measure) {
    set_sleep_mode(SLEEP_MODE_IDLE);
    sleep_enable();
    sleep_cpu();    // ← Timer1で起きる
    sleep_disable();
  }

  // ===== ここへ来たら、Timer1が1秒ごとに起こした証拠 =====
  if (!g_do_measure) {
    return;         // 念のため
  }
  g_do_measure = false;

  // ===== 1秒ごとの測定処理（元の処理をそのまま置く） =====
  runSensorScanAndInference();   // ← あなたのADC読み込み＋推論＋LCD更新処理

  // ===== 処理が終わったので、次の割り込みまでスリープへ =====
}

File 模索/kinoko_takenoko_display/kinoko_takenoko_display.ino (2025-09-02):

#include <Wire.h>
#define LCD_ADRS 0x3E  // AQM1602XA I2Cアドレス
#define LCD_COLS 16

// 表示状態
enum DispState : uint8_t {
  STATE_OFF = 0,
  STATE_TAKENOKO = 1,   // 旧 HALF_ON
  STATE_KINOKO  = 2,    // 旧 FULL_ON
  STATE_CHAR_SAMPLE = 3
};
DispState g_state = STATE_OFF;

int g_contrast = 0;    // 0..63, 'c'で+7

// ---- 低レベル送信 ----
static inline void writeCommand(uint8_t cmd) {
  Wire.beginTransmission(LCD_ADRS);
  Wire.write(0x00);  // Co=0, RS=0
  Wire.write(cmd);
  Wire.endTransmission();
  delay(2);
}
static inline void writeData(uint8_t data) {
  Wire.beginTransmission(LCD_ADRS);
  Wire.write(0x40);  // Co=0, RS=1
  Wire.write(data);
  Wire.endTransmission();
  delay(1);
}

// ---- 便利ヘルパー ----
static inline void setCursor(uint8_t col, uint8_t row) {
  writeCommand(0x80 | (row ? (0x40 + col) : col)); // row: 0=上,1=下
}
static inline void writeAsciiStr(const char* s) {
  while (*s) writeData((uint8_t)*s++);
}
static inline void writeSpaces(uint8_t n) {
  for (uint8_t i = 0; i < n; ++i) writeData(0x20);
}
static inline void putCGRAM(uint8_t code) { // 0..7
  writeData(code & 0x07);
}

// ---- 初期化 ----
void initLCD() {
  delay(50);
  writeCommand(0x38);     // Function set
  writeCommand(0x39);     // IS=1
  writeCommand(0x14);     // Bias/OSC
  writeCommand(0x70 | (g_contrast & 0x0F));          // Contrast low
  writeCommand(0x5C | ((g_contrast >> 4) & 0x03));   // Contrast high, Icon off, Booster on
  writeCommand(0x6C);     // Follower ON
  delay(200);
  writeCommand(0x38);     // IS=0
  writeCommand(0x0C);     // Display ON
  writeCommand(0x01);     // Clear
  delay(2);
  writeCommand(0x06);     // Entry mode
}

// ---- CGRAM定義（0〜7） ----
void defineCGRAMAll() {
  const uint8_t CGRAMs[8][8] = {
    { 0x03, 0x0F, 0x0C, 0x18, 0x18, 0x18, 0x1C, 0x00 }, // 0
    { 0x18, 0x0C, 0x02, 0x01, 0x01, 0x02, 0x0C, 0x00 }, // 1
    { 0x1F, 0x1F, 0x0E, 0x00, 0x00, 0x00, 0x00, 0x00 }, // 2
    { 0x18, 0x04, 0x12, 0x11, 0x09, 0x09, 0x06, 0x00 }, // 3
    { 0x01, 0x03, 0x06, 0x05, 0x0B, 0x0E, 0x1D, 0x00 }, // 4
    { 0x10, 0x18, 0x0C, 0x14, 0x0A, 0x1E, 0x1B, 0x00 }, // 5
    { 0x1D, 0x1D, 0x1B, 0x1F, 0x04, 0x04, 0x07, 0x00 }, // 6
    { 0x17, 0x0F, 0x0F, 0x1F, 0x04, 0x04, 0x1C, 0x00 }  // 7
  };
  for (uint8_t ch = 0; ch < 8; ++ch) {
    writeCommand(0x40 | ((ch & 0x07) << 3));   // CGRAM base addr
    for (uint8_t r = 0; r < 8; ++r) writeData(CGRAMs[ch][r] & 0x1F);
  }
}

// ---- 画面クリア ----
void lcdClearAll() {
  // 空白で埋めてから Clear でチラつき抑制
  setCursor(0, 0); for (int i=0; i<LCD_COLS; ++i) writeData(0x20);
  setCursor(0, 1); for (int i=0; i<LCD_COLS; ++i) writeData(0x20);
  writeCommand(0x01);
  delay(2);
}

// ---- PATTERN: KINOKO（旧 FULL_ON） ----
// 上段：CGRAM0,1 , 空白×3 , "Kinoko"(6) , 空白×3 , CGRAM0,1
// 下段：CGRAM2,3 , 空白×12 , CGRAM2,3
void drawKinokoPattern() {
  lcdClearAll();

  // 上段
  setCursor(0, 0);
  putCGRAM(0); putCGRAM(1);         // 左端 CGRAM0,1
  writeSpaces(3);
  writeAsciiStr("Kinoko");          // 6
  writeSpaces(3);
  putCGRAM(0); putCGRAM(1);         // 右端 CGRAM0,1

  // 下段
  setCursor(0, 1);
  putCGRAM(2); putCGRAM(3);         // 左端 CGRAM2,3
  writeSpaces(12);
  putCGRAM(2); putCGRAM(3);         // 右端 CGRAM2,3
}

// ---- PATTERN: TAKENOKO（旧 HALF_ON） ----
// 上段：CGRAM4,5 , 空白×2 , "Takenoko"(8) , 空白×2 , CGRAM4,5
// 下段：CGRAM6,7 , 空白×12 , CGRAM6,7
void drawTakenokoPattern() {
  lcdClearAll();

  // 上段
  setCursor(0, 0);
  putCGRAM(4); putCGRAM(5);         // 左端 CGRAM4,5
  writeSpaces(2);
  writeAsciiStr("Takenoko");        // 8
  writeSpaces(2);
  putCGRAM(4); putCGRAM(5);         // 右端 CGRAM4,5

  // 下段
  setCursor(0, 1);
  putCGRAM(6); putCGRAM(7);         // 左端 CGRAM6,7
  writeSpaces(12);
  putCGRAM(6); putCGRAM(7);         // 右端 CGRAM6,7
}

// ---- サンプル（変更なし） ----
void drawCharSample() {
  lcdClearAll();
  const char line1[17] = "ABCDEFGHIJKLMNOP";
  const char line2[17] = "QRSTUVWXYZabcdef";
  setCursor(0, 0); for (int i=0;i<LCD_COLS;i++) writeData(line1[i]);
  setCursor(0, 1); for (int i=0;i<LCD_COLS;i++) writeData(line2[i]);
}

// ---- コントラスト ----
void setContrast(int val) {
  val = constrain(val, 0, 63);
  writeCommand(0x39); // IS=1
  writeCommand(0x70 | (val & 0x0F));
  writeCommand(0x5C | ((val >> 4) & 0x03));
  writeCommand(0x38); // IS=0
}

// ---- 状態適用 ----
void applyState() {
  switch (g_state) {
    case STATE_OFF:
      lcdClearAll();        Serial.println(F("STATE_OFF")); break;
    case STATE_TAKENOKO:
      drawTakenokoPattern();Serial.println(F("STATE_TAKENOKO: [4,5]..Takenoko..[4,5] / [6,7]....[6,7]")); break;
    case STATE_KINOKO:
      drawKinokoPattern();  Serial.println(F("STATE_KINOKO: [0,1]..Kinoko..[0,1] / [2,3]....[2,3]")); break;
    case STATE_CHAR_SAMPLE:
      drawCharSample();     Serial.println(F("STATE_CHAR_SAMPLE")); break;
  }
}

void setup() {
  Serial.begin(115200);
  Wire.begin();             // Due: SDA=20, SCL=21
  initLCD();
  defineCGRAMAll();
  applyState();    // 初期 STATE_OFF
  Serial.println(F("Ready. 'r': OFF -> TAKENOKO -> KINOKO -> SAMPLE,  'c': Contrast +7"));
}

void loop() {
  if (Serial.available()) {
    char c = Serial.read();
    if (c == 'r' || c == 'R') {
      g_state = static_cast<DispState>((g_state + 1) % 4);
      applyState();
    }
    else if (c == 'c' || c == 'C') {
      g_contrast += 7;
      if (g_contrast > 63) g_contrast = 0;
      setContrast(g_contrast);
      Serial.print(F("Contrast = "));
      Serial.println(g_contrast);
    }
  }
}

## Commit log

2025-07-08 概要を追記
2025-07-08 概要修正、省電力の取り組み追加
2025-08-31 電流計測用のソフトウェア格納
    [消費電流まとめ.xlsx]
2025-08-31 Qiita用の記事追加
2025-09-02 きのこたけのこ表示確認用意
2025-09-08 回路図追加
2025-09-08 回路図反映
2025-09-10 説明追加
2025-09-10 LCD文字生成アプリ追加
2025-09-23 OLEDのテストプログラム格納
    [OLED消費電力チェック.xlsx]
2025-09-25 3Dデータ格納
    [LCD台.stl, きのこ_ハーフ.stl, たけのこ_ハーフ.stl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]
2025-10-29 LCDテスト用のプログラム追加
2025-10-29 名前修正
2025-11-23 センサ読み込み模索
2025-11-23 データ採取用ソフトウェアと採取データ
    [kinoko1(light).csv, kinoko1(light_dark).csv, kinoko1(light_high).csv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]
2025-11-23 データまとめ
    [まとめ.csv]
2025-11-24 モデル生成
    [kinoko_takenoko_merged.csv, normalized_from_raw.csv]
2025-11-24 ファイルの説明追記
2025-11-24 ファイル構造修正
2025-11-24 分類結果表示に問題ないことを確認
2025-11-24 演算時間計測用の改造
2025-11-24 分析結果格納
    [classification_time.xls, current_active.xls, current_active.xlsx]
2025-11-24 グラフ追加
    [current_active.xlsx]
2025-11-25 leafony固定台
    [Leafony固定治具.stl]
2025-11-25 D5デバッグ無効(会場に持っていく版)
2025-12-01 オシロ分析結果まとめ
    [classification_time.xls, current_active.xlsx]
2025-12-02 説明追記
2025-12-02 バーを削除
2025-12-02 英語説明など追記
2026-03-23 概要が分かるように情報更新
2026-04-16 発表用のデータまとめ
